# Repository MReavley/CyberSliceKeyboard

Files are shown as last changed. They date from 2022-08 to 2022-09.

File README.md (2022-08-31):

# CyberSlice Keyboard

Picture of the CyberSlice42

42/36 key split keyboard using RP2040, with the same layout (in 36 key configuration) as my previous design, the Slice 36. The goal was primarily to experience designing a microcontroller directly on the PCB, but I also wanted to try to take advantage of the large number of GPIO pins on the RP2040. There are 8 additional GPIO (2 analog capable) on the PCB with the intention of adding functionality through magnetic pogo connectors, but that is still a work in progress. 

## Features

- Reversible PCB designed for PCB assembly services  
- RP2040 per side, with 16MB of flash  
- Laser cut aluminium plate, custom designed 3D printed case with magnets  
- Footprints for magnetic pogo connectors on each side
- Breakaway tabs convert from 42 to 36 key  

Picture of the CyberSlice42 plugged in

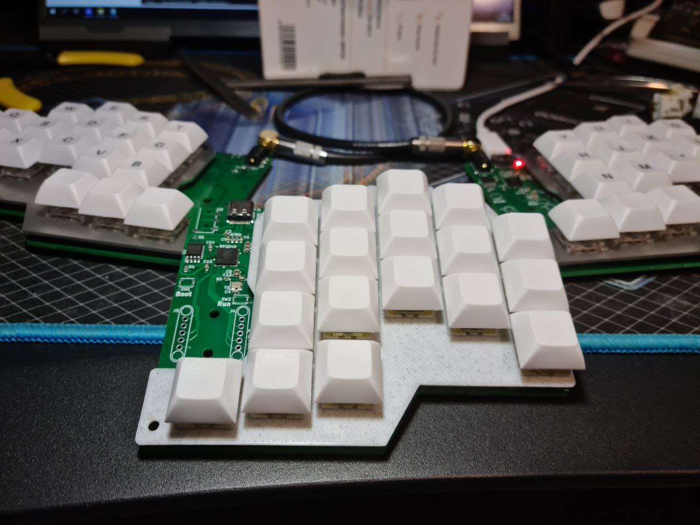
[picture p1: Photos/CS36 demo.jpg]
Picture of the CyberSlice36 (and CS42 behind it)


## If you want to build:
This board is just a prototype, and there are a couple pointers to watch out for:

Reversible PCB: Since the PCB is reversible, solder on the trrs connector on opposite sides of the PCB for each half. The USB-C connector for the left half will be on the bottom side, which does necessitate taller rubber feet unfortunately.

Components on the rear:  
These components will not be assembled by basic PCBa, but the parts can be scavenged from spare assembled PCBs (per side)
- C7 (100nF 0603 MLCC capacitor)
- R1 and R2 (5.1k 0603 resistors)
- R12 and R13 (Optional, 4.7k 0603 pullups for split over I2C, not needed for UART)

Additional components:
- PJ320D trrs connectors (x1 per side), solder on opposite side of PCB for the different halves
- 2.54mm magnetic pogo connectors (5 contacts) (2x per side) (optional, can solder directly instead)
- 6mm diameter x 3mm height magnets x6 per side for case (optional, can use screw holes instead)

Reset and boot switches may need to be renamed in the BOM file (not using SW1 and SW2) for them to be auto-selected by PCBa service  
- Otherwise shorting the pads on the PCB will have the same effect

Case:
- Tolerances were very loose on my case, but this does depend on the printer
- Ideally, one would redesign the plate to mount directly to the case (add screw holes)
- Tolerance for the magnet holes can be a bit too tight, probably increase from 6 to 6.1 or 6.2mm diameter

Picture of the CyberSlice42 case rear

## Things to improve

- Rename the reset and boot switches from SW1 and SW2 to something else to not clash with the names of the switches (caused me to make a mistake in my order)  
- Shift the few SMD parts on the back side to the front for PCBa  
- Add a few more LEDs for status indicators on the PCB itself  
- Change the plate the design for better mounting of PCB and plate to case, or alternatively integrate the plate into the case  

Picture of the CyberSlice42 pcb rear

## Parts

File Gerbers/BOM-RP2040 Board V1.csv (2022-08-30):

Comment | Designator | Footprint | LCSC
100n | C10,C11,C12,C13,C14,C15,C3,C7,C8,C9 | C_0603_1608Metric_Pad1.08x0.95mm_HandSolder | C14663
1u | C16,C6 | C_0603_1608Metric_Pad1.08x0.95mm_HandSolder | C1592
USB_C_Receptacle_USB2.0 | J1 | USB_C_Receptacle_HRO_TYPE-C-31-M-12 | C165948
RP2040 | U3 | RP2040 | C2040
1k | R3,R4,R6 | R_0603_1608Metric | C21190
D | D10,D11,D12,D13,D14,D15,D16,D17,D18,D19,D2,D20,D21,D22,D3,D4,D5,D6,D7,D8,D9 | D_SOD-323_HandSoldering | C2128
SW_SPST | SW1,SW2 | SW_SPST_PTS810 | C221895
5.1k | R1,R10,R11,R2,R9 | R_0603_1608Metric | C23186
27 | R7,R8 | R_0603_1608Metric_Pad0.98x0.95mm_HandSolder | C25190
12MHz | Y1 | Crystal_SMD_3225-4Pin_3.2x2.5mm | C390764
22u | C1,C2 | C_0603_1608Metric | C59461
AMS1117-3.3 | U1 | SOT-223-3_TabPin2 | C6186
RED | D1 | LED_0603_1608Metric | C84263
27p | C4,C5 | C_0603_1608Metric | C92670
W25Q128JVS | U2 | SOIC-8_5.23x5.23mm_P1.27mm | C97521
Cherry_Doublesided | Sw14 | SW_MX_reversible
Cherry_Doublesided | Sw7 | SW_MX_reversible
Cherry_Doublesided | Sw3 | SW_MX_reversible
Cherry_Doublesided | Sw6 | SW_MX_reversible
Cherry_Doublesided | Sw12 | SW_MX_reversible
Cherry_Doublesided | Sw17 | SW_MX_reversible
Cherry_Doublesided | Sw8 | SW_MX_reversible
Cherry_Doublesided | Sw9 | SW_MX_reversible
Cherry_Doublesided | Sw20 | SW_MX_reversible
Conn_01x05_MountingPin | J4 | Magnet 5pin 2.54mm pitch through hole
Cherry_Doublesided | Sw21 | SW_MX_reversible
Cherry_Doublesided | Sw11 | SW_MX_reversible
DNP | R5 | R_0603_1608Metric
Cherry_Doublesided | Sw2 | SW_MX_reversible
Cherry_Doublesided | Sw1 | SW_MX_reversible
Cherry_Doublesided | Sw4 | SW_MX_reversible
Cherry_Doublesided | Sw13 | SW_MX_reversible
Cherry_Doublesided | Sw19 | SW_MX_reversible
Cherry_Doublesided | Sw15 | SW_MX_reversible
Conn_01x05_MountingPin | J5 | Magnet 5pin 2.54mm pitch through hole
AudioJack4 | J2 | Jack_3.5mm_PJ320D_Horizontal
Cherry_Doublesided | Sw10 | SW_MX_reversible
Cherry_Doublesided | Sw5 | SW_MX_reversible
Cherry_Doublesided | Sw18 | SW_MX_reversible
Cherry_Doublesided | Sw16 | SW_MX_reversible
AudioJack4 | J3 | Jack_3.5mm_PJ320D_Horizontal
DNP | R12 | R_0805_2012Metric_Pad1.20x1.40mm_HandSolder
DNP | R13 | R_0805_2012Metric_Pad1.20x1.40mm_HandSolder

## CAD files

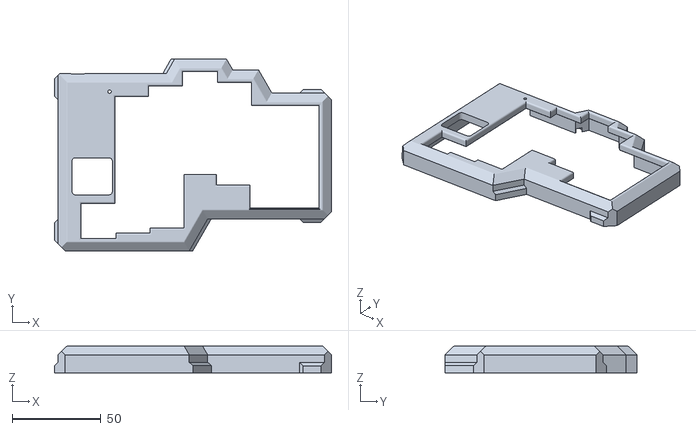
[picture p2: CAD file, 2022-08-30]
Plate and Case/CyberSlice42_case_top .STL
156.0 x 108.0 x 15.2

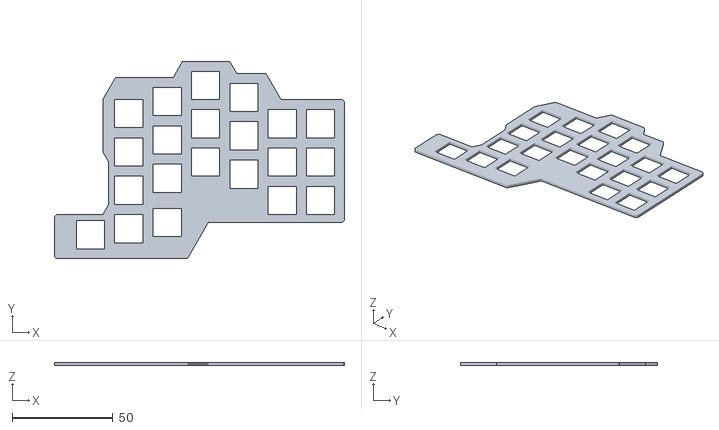
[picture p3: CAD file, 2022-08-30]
Plate and Case/CyberSlice42_plate .STL
144.0 x 98.0 x 1.60

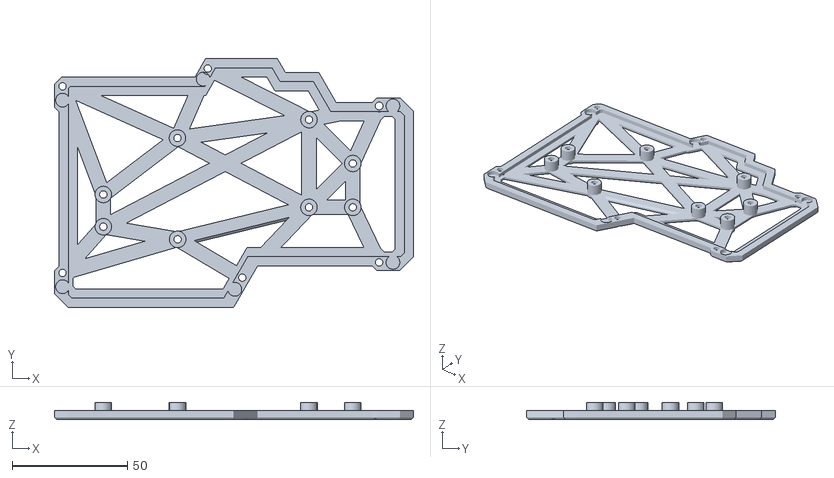
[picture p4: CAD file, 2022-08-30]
Plate and Case/CyberSlice42_case_bottom .STL
156.0 x 108.0 x 7.50

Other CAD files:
Plate and Case/CyberSlice42_plate.DXF

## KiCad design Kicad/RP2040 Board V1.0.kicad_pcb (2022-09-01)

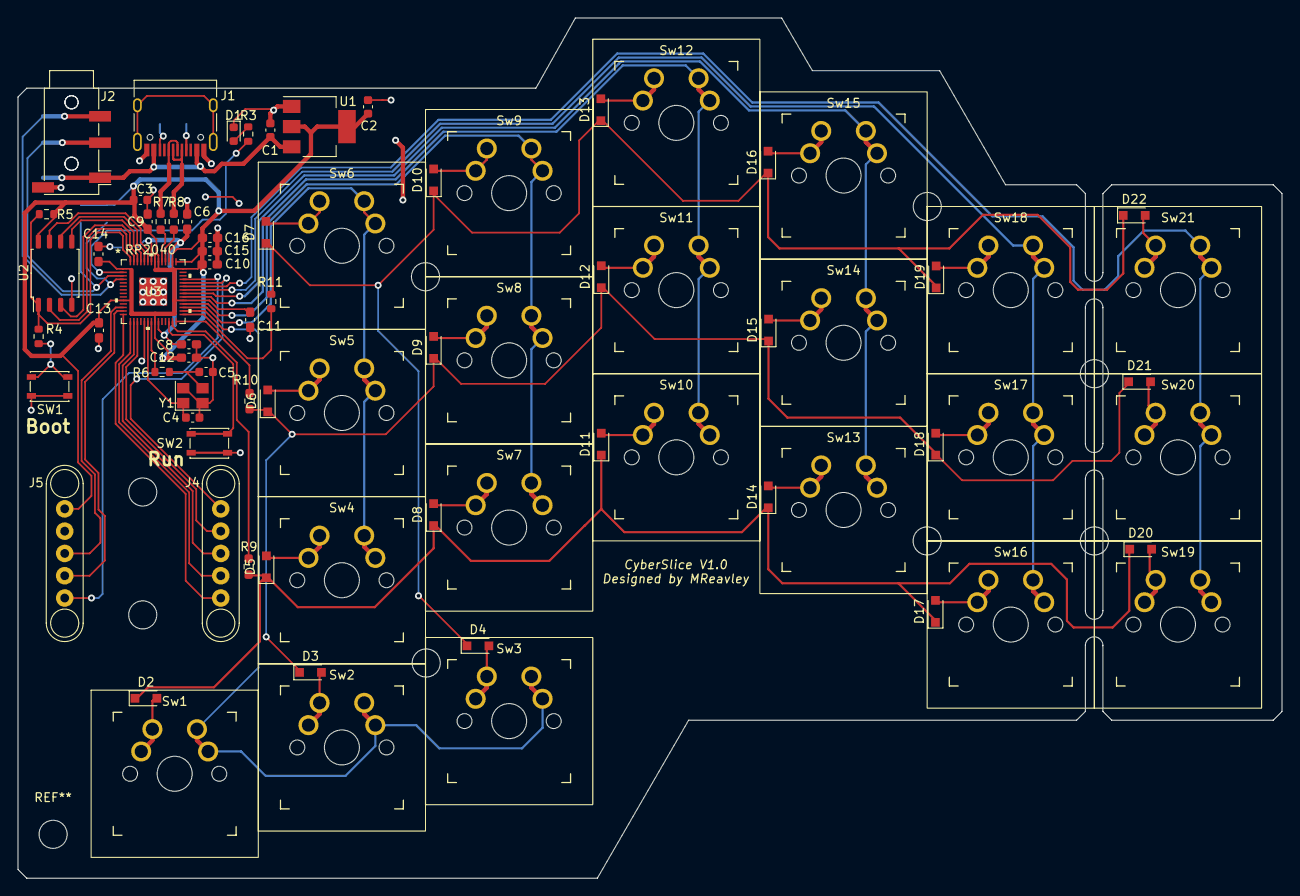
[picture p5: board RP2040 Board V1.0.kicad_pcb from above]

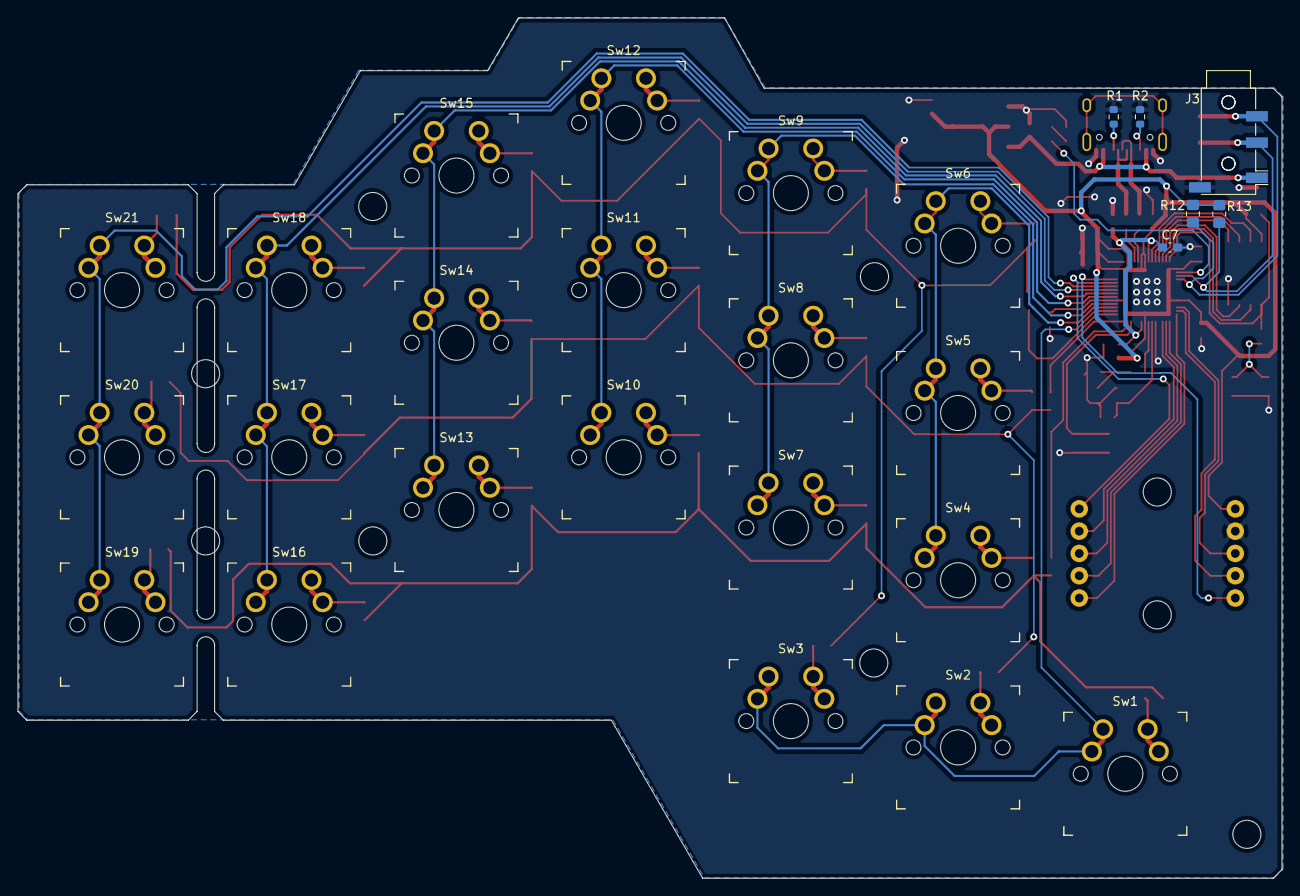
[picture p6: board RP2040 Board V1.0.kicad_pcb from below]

Board: 2 copper layers, 144.0 x 98.0 mm, 83 parts (6 on the bottom side), 67 nets.

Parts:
C1, C2: 22u; C_0603_1608Metric
C3: 100n; C_0603_1608Metric
C4, C5: 27p; C_0603_1608Metric
C6, C16: 1u; C_0603_1608Metric_Pad1.08x0.95mm_HandSolder
C7, C8, C9, C10, C11, C12, C13, C14, C15: 100n; C_0603_1608Metric_Pad1.08x0.95mm_HandSolder
D1: RED; LED_0603_1608Metric
D2, D3, D4, D5, D6, D7, D8, D9, D10, D11, D12, D13, D14, D15, D16, D17, D18, D19, D20, D21, D22: D; D_SOD-323_HandSoldering
J1: USB_C_Receptacle_USB2.0; USB_C_Receptacle_HRO_TYPE-C-31-M-12
J2, J3: AudioJack4; Jack_3.5mm_PJ320D_Horizontal
J4, J5: Conn_01x05_MountingPin; Magnet 5pin 2.54mm pitch through hole
R1, R2, R11: 5.1k; R_0603_1608Metric
R3, R4, R6: 1k; R_0603_1608Metric
R5: DNP; R_0603_1608Metric
R7, R8: 27; R_0603_1608Metric_Pad0.98x0.95mm_HandSolder
R9, R10: 5.1k; R_0603_1608Metric_Pad0.98x0.95mm_HandSolder
R12, R13: DNP; R_0805_2012Metric_Pad1.20x1.40mm_HandSolder
SW1, SW2: SW_SPST; SW_SPST_PTS810
Sw1, Sw2, Sw3, Sw4, Sw5, Sw6, Sw7, Sw8, Sw9, Sw10, Sw11, Sw12, Sw13, Sw14, Sw15, Sw16, Sw17, Sw18, Sw19, Sw20, Sw21: Cherry_Doublesided; SW_MX_reversible
U1: AMS1117-3.3; SOT-223-3_TabPin2
U2: W25Q128JVS; SOIC-8_5.23x5.23mm_P1.27mm
U3: RP2040
Y1: 12MHz; Crystal_SMD_3225-4Pin_3.2x2.5mm

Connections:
+1V1: C6.1, C7.1, C8.1, U3.23 (DVDD), U3.45 (VREG_VOUT), U3.50 (DVDD)
+3V3: C2.1, C3.1, C9.1, C10.1, C11.1, C12.1, C13.1, C14.1, C15.1, C16.1, J5.1, R5.2, R12.1, R13.1, U1.2 (VO), U2.8 (VCC), U3.1 (IOVDD), U3.10 (IOVDD), U3.22 (IOVDD), U3.33 (IOVDD), U3.42 (IOVDD), U3.43 (ADC_AVDD), U3.44 (VREG_IN), U3.48 (USB_VDD), U3.49 (IOVDD)
/QSPICLK: U2.6 (CLK), U3.52 (QSPI_SCLK)
/QSPISD0: U2.5 (DI(IO0)), U3.53 (QSPI_SD0)
/QSPISD2: U2.3 (IO2), U3.54 (QSPI_SD2)
/QSPISD3: U2.7 (IO3), U3.51 (QSPI_SD3)
/QSPISS: R4.1, R5.1, U2.1 (~CS), U3.56 (QSPI_SS)
/SQPISD1: U2.2 (DO(IO1)), U3.55 (QSPI_SD1)
Col 0: Sw1.2 (SW), Sw2.2 (SW), Sw3.2 (NW), U3.30 (GPIO19)
Col 1: Sw4.2 (SW), Sw5.2 (NW), Sw6.2 (NW), U3.31 (GPIO20)
Col 2: Sw7.2 (SW), Sw8.2 (NW), Sw9.2 (NW), U3.32 (GPIO21)
Col 3: Sw10.2 (SW), Sw11.2 (NW), Sw12.2 (NW), U3.34 (GPIO22)
Col 4: Sw13.2 (NW), Sw14.2 (NW), Sw15.2 (NW), U3.35 (GPIO23)
Col 5: Sw16.2 (SW), Sw17.2 (NW), Sw18.2 (NW), U3.36 (GPIO24)
Col 6: Sw19.2 (SW), Sw20.2 (SW), Sw21.2 (NW), U3.37 (GPIO25)
Data+: J1.A6 (D+), J1.B6 (D+), R7.2
Data-: J1.A7 (D-), J1.B7 (D-), R8.2
GND: C1.2, C2.2, C3.2, C4.2, C5.2, C6.2, C7.2, C8.2, C9.2, C10.2, C11.2, C12.2, C13.2, C14.2, C15.2, C16.2, D1.1 (K), J1.A1 (GND), J1.A12 (GND), J1.B1 (GND), J1.B12 (GND), J2.S, J3.S, J5.2, R1.1, R2.1, SW1.1 (A), SW2.1 (A), U1.1 (GND), U2.4 (GND), U3.19 (TESTEN), U3.57 (GND), Y1.2, Y1.4
LED: R3.2, U3.2 (GPIO0)
unnamed: C4.1, U3.20 (XIN), Y1.1
unnamed: C5.1, R6.2, Y1.3
unnamed: D1.2 (A), R3.1
unnamed: D2.2 (A), Sw1.1 (NE)
unnamed: D3.2 (A), Sw2.1 (NE)
unnamed: D4.2 (A), Sw3.1 (NE)
unnamed: D5.2 (A), Sw4.1 (NE)
unnamed: D6.2 (A), Sw5.1 (NE)
unnamed: D7.2 (A), Sw6.1 (NE)
unnamed: D8.2 (A), Sw7.1 (NE)
unnamed: D9.2 (A), Sw8.1 (NE)
unnamed: D4.1 (K), D7.1 (K), D10.1 (K), D13.1 (K), D16.1 (K), D19.1 (K), D22.1 (K), R11.2
unnamed: D10.2 (A), Sw9.1 (NE)
unnamed: D2.1 (K), D5.1 (K), D8.1 (K), D11.1 (K), D14.1 (K), D17.1 (K), D20.1 (K), R9.2
unnamed: D11.2 (A), Sw10.1 (NE)
unnamed: D3.1 (K), D6.1 (K), D9.1 (K), D12.1 (K), D15.1 (K), D18.1 (K), D21.1 (K), R10.2
unnamed: D12.2 (A), Sw11.1 (NE)
unnamed: D13.2 (A), Sw12.1 (NE)
unnamed: D14.2 (A), Sw13.1 (NE)
unnamed: D15.2 (A), Sw14.1 (NE)
unnamed: D16.2 (A), Sw15.1 (NE)
unnamed: D17.2 (A), Sw16.1 (NE)
unnamed: D18.2 (A), Sw17.1 (NE)
unnamed: D19.2 (A), Sw18.1 (NE)
unnamed: D20.2 (A), Sw19.1 (NE)
unnamed: D21.2 (A), Sw20.1 (NE)
unnamed: D22.2 (A), Sw21.1 (NE)
unnamed: J1.A5 (CC1), R1.2
unnamed: J1.B5 (CC2), R2.2
unnamed: J2.R2, J3.R2, R12.2, U3.4 (GPIO2)
unnamed: J4.1, U3.38 (GPIO26_ADC0)
unnamed: J4.2, U3.17 (GPIO14)
unnamed: J4.3, U3.16 (GPIO13)
unnamed: J4.4, U3.15 (GPIO12)
unnamed: J4.5, U3.14 (GPIO11)
unnamed: J5.3, U3.12 (GPIO9)
unnamed: J5.4, U3.13 (GPIO10)
unnamed: J5.5, U3.39 (GPIO27_ADC1)
unnamed: R4.2, SW1.2 (B)
unnamed: R6.1, U3.21 (XOUT)
unnamed: R7.1, U3.47 (USB_DP)
unnamed: R8.1, U3.46 (USB_DM)
unnamed: SW2.2 (B), U3.26 (RUN)
unnamed: J2.R1, J3.R1, R13.2, U3.3 (GPIO1)
Row 0: R9.1, U3.27 (GPIO16)
Row 1: R10.1, U3.28 (GPIO17)
Row 2: R11.1, U3.29 (GPIO18)
VBUS: C1.1, J1.A4 (VBUS), J1.A9 (VBUS), J1.B4 (VBUS), J1.B9 (VBUS), J2.T, J3.T, U1.3 (VI)

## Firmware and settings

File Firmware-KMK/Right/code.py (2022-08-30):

import board

from kb import KMKKeyboard

import adafruit_pioasm
import neopixel

from digitalio import DigitalInOut, Direction ,Pull

#from kmk.kmk_keyboard import KMKKeyboard
from kmk.keys import KC
from kmk.matrix import DiodeOrientation
from kmk.modules.split import Split, SplitSide, SplitType
from kmk.modules.layers import Layers
from kmk.modules.modtap import ModTap
from kmk.modules.mouse_keys import MouseKeys
from kmk.extensions.media_keys import MediaKeys
from kmk.extensions.lock_status import LockStatus
from kmk.handlers.sequences import simple_key_sequence
from kmk.extensions.RGB import RGB

#pixel_pin = board.NEOPIXEL
#num_pixels = 1
rgb_ext = RGB(pixel_pin = board.NEOPIXEL, num_pixels=1, hue_default= 0, val_limit=10,
              val_default=10, hue_step=18)
#rgb_ext.rgb_config['hue_default']= 200
#rgb_ext.rgb_config['val_limit'] = 50

#pixels=neopixel.NeoPixel(pixel_pin, num_pixels, brightness = 0.05, auto_write=False)

#pixels[0]= (0,255,255)
#pixels.show()

red = DigitalInOut(board.LED_RED)
red.direction = Direction.OUTPUT
red.value = 1

green = DigitalInOut(board.LED_GREEN)
green.direction = Direction.OUTPUT
green.value = 1

blue = DigitalInOut(board.LED_BLUE)
blue.direction = Direction.OUTPUT
blue.value = 1


keyboard = KMKKeyboard()

modtap = ModTap()

mousekeys=MouseKeys()




split_side = SplitSide.RIGHT
#split_side = SplitSide.LEFT

split = Split(split_flip=True,split_type=SplitType.UART, split_side=split_side, use_pio=True,
split_target_left=False, target_left=False, data_pin= board.D5,
data_pin2=board.D4)

layers_ext = Layers()
locks = LockStatus()


keyboard.modules.append(split)
keyboard.modules.append(layers_ext)
keyboard.modules.append(modtap)
keyboard.modules.append(mousekeys)
keyboard.extensions.append(MediaKeys())
keyboard.extensions.append(locks)
keyboard.extensions.append(rgb_ext)

# Cleaner key names
_______ = KC.TRNS
XXXXXXX = KC.NO

QWERTY = simple_key_sequence((KC.TO(0),KC.RGB_M_P))
LOWER = KC.MO(1)
RAISE = KC.MO(2)
COMBO = KC.MO(3)
GAME =  simple_key_sequence((KC.TO(4),KC.RGB_M_BR))
GAME2 = KC.MO(5)

#Press and hold for modifiers
HLCtrl = KC.MT(KC.Z, KC.LCTL)
HLAlt = KC.MT(KC.X, KC.LALT)
HLGUI = KC.MT(KC.C, KC.LGUI)

HRCtrl = KC.MT(KC.SLSH, KC.LCTL)
HRAlt = KC.MT(KC.DOT, KC.LALT)
HRGUI = KC.MT(KC.COMM, KC.LGUI)


#Macros 
Scnshot = KC.LGUI(KC.LSFT(KC.S))
TManager = KC.LCTL(KC.LSFT(KC.ESC))
    
NTab = KC.LCTL(KC.TAB)
PTab = KC.LCTL(KC.LSFT(KC.TAB))

Undo = KC.LCTL(KC.Z)

RunPython = KC.LCTL(KC.LSFT(KC.B))

keyboard.keymap = [
    [  #QWERTY
        KC.Q,    KC.W,    KC.E,    KC.R,    KC.T,             KC.Y,    KC.U,    KC.I,    KC.O,   KC.P,    \
        KC.A,    KC.S,    KC.D,    KC.F,    KC.G,             KC.H,    KC.J,    KC.K,    KC.L, KC.QUOT,   \
        HLCtrl,  HLAlt,   KC.C,    KC.V,    KC.B,             KC.N,    KC.M,   HRGUI,   HRAlt,  HRCtrl,   \
                        KC.LSFT,   KC.SPC,  LOWER,            RAISE,   KC.BSPC,  KC.ENT,
    ],
    [  #LOWER
        KC.ESC,  PTab,    KC.UP,   NTab,    KC.PERC,          KC.PLUS, KC.N7,  KC.N8,  KC.N9,  KC.EQL, \
        KC.TAB,  KC.LEFT, KC.DOWN, KC.RGHT, KC.LPRN,          KC.MINS, KC.N4,  KC.N5,  KC.N6,  KC.ASTR, \
          Undo,  KC.ENT,  KC.DEL,  KC.BSPC, KC.RPRN,          KC.N0,   KC.N1,  KC.N2,  KC.N3,  XXXXXXX, \
                          XXXXXXX, KC.LGUI, LOWER,            COMBO,   KC.DEL, KC.TAB,
    ],
    [  #RAISE
        KC.TILD,   KC.EXLM, KC.AT,   KC.HASH, KC.DLR,         KC.MB_MMB, KC.MB_LMB, KC.MS_UP, KC.MB_RMB, KC.AMPR, \
        KC.PGUP,   KC.VOLU, KC.PIPE, KC.LBRC, KC.LCBR,        KC.MW_UP,  KC.MS_LT,  KC.MS_DN, KC.MS_RT,  KC.CIRC, \
        KC.PGDOWN, KC.VOLD, PTab,    KC.RBRC, KC.RCBR,        KC.MW_DN,  KC.COLN,   KC.SCLN,  KC.UNDS,   KC.BSLS, \
                            KC.LSFT, XXXXXXX, COMBO,          RAISE,     XXXXXXX,   XXXXXXX,
    ],
    
    [  #COMBO
        KC.GRV , KC.F1,   KC.F2,   KC.F3,   KC.F4,            KC.HOME, XXXXXXX, XXXXXXX,XXXXXXX,TManager, \
        KC.INS,  KC.F5,   KC.F6,   KC.F7,   KC.F8,            KC.END, XXXXXXX, XXXXXXX, XXXXXXX,Scnshot,   \
        KC.NLCK, KC.F9,   KC.F10,  KC.F11,  KC.F12,           KC.MW_DN,XXXXXXX,XXXXXXX,XXXXXXX,RunPython,         \
                          GAME,    XXXXXXX, XXXXXXX,          XXXXXXX,XXXXXXX,XXXXXXX,
    ],
    
    [  #GAME
        KC.LALT , KC.Q , KC.W , KC.E , KC.R,     KC.MB_MMB, KC.MB_LMB, KC.MS_UP,KC.MB_RMB,XXXXXXX,
        KC.TAB  , KC.A, KC.S,  KC.D  , KC.F ,    KC.MW_UP, KC.MS_LT, KC.MS_DN, KC.MS_RT,XXXXXXX, 
        KC.LCTL, KC.Z, KC.X, KC.C, KC.V,       KC.MW_DN,XXXXXXX,XXXXXXX,XXXXXXX,XXXXXXX,
                       KC.LSFT, KC.SPC, GAME2,    XXXXXXX,   XXXXXXX,  QWERTY, 
    ],
    
    [   #GAME2
        KC.ESC,   KC.I, KC.T, KC.N1,  KC.N4,         XXXXXXX, XXXXXXX,  XXXXXXX, XXXXXXX,  XXXXXXX, \
        KC.CAPS,  KC.B, KC.G, KC.N2,  KC.N5,         XXXXXXX, XXXXXXX,  XXXXXXX, XXXXXXX,  XXXXXXX, \
        XXXXXXX,  KC.J, KC.M, KC.N3,  KC.N6,         XXXXXXX, XXXXXXX, XXXXXXX,XXXXXXX,  XXXXXXX, \
                      XXXXXXX, XXXXXXX,XXXXXXX,         XXXXXXX,  XXXXXXX,  XXXXXXX,

        
        
    ]   
]

class _LockStatus(LockStatus):
    def during_bootup(self, sandbox):
        self.caps_lock_led = blue
    def after_hid_send(self, sandbox):
        super().after_hid_send(sandbox)
        self.caps_lock_led.value = not(self.get_caps_lock())
    
keyboard.extensions.append(_LockStatus())




if __name__ == '__main__':
    keyboard.go()

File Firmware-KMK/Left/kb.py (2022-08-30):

import board

from kmk.kmk_keyboard import KMKKeyboard as _KMKKeyboard
from kmk.matrix import DiodeOrientation


class KMKKeyboard(_KMKKeyboard):
    col_pins = (board.GP19, board.GP20, board.GP21, board.GP22, board.GP23, board.GP24, board.GP25)
    row_pins = (board.GP16, board.GP17, board.GP18)
    diode_orientation = DiodeOrientation.COL2ROW
    #columns_to_anodes=True,
    #pull=True


    coord_mapping = [
     6,  5,  4,  3,  2,  1,    36, 37, 38, 39, 40, 41, 
    13, 12, 11, 10,  9,  8,    29, 30, 31, 32, 33, 34,
    20, 19, 18, 17, 16, 15,    22, 23, 24, 25, 26, 27,
                14,  7,  0,    21, 28, 35    ]
                

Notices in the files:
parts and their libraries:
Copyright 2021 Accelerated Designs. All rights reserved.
